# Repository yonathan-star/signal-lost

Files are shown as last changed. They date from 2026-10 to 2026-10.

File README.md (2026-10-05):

# signal-lost
Signal Lost: an interactive PCB radio that tunes into fictional transmissions

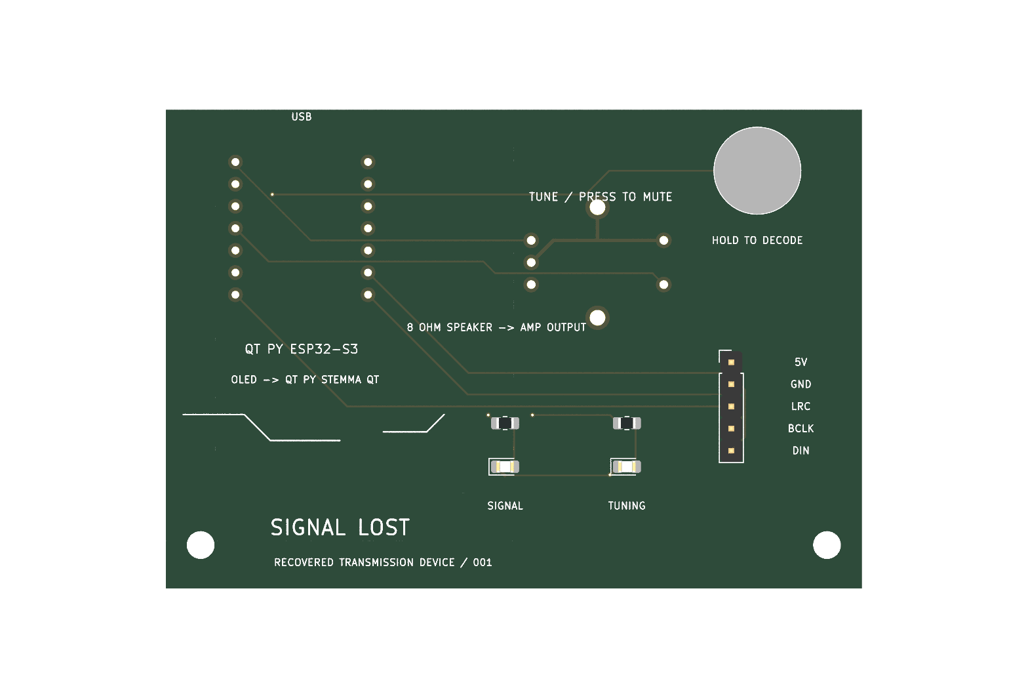
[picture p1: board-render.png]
Signal Lost PCB front render


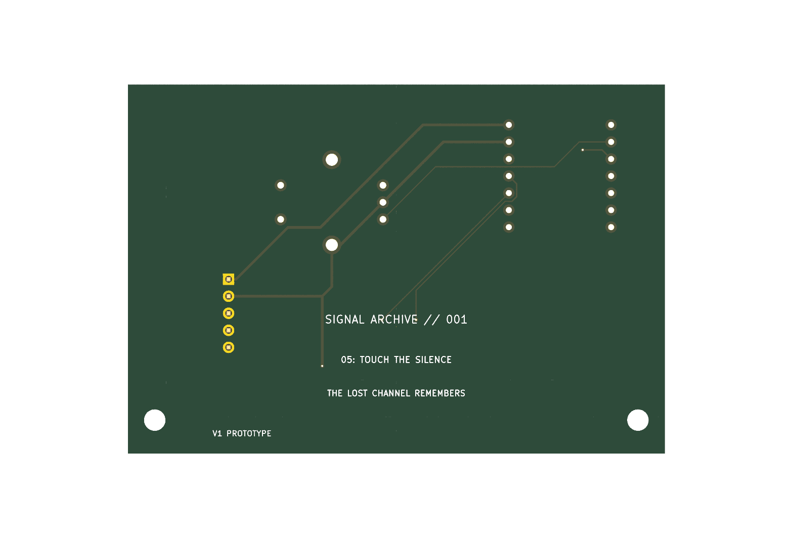
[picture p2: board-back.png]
Signal Lost PCB back render


## Engineering prototype

This repository includes an AI-assisted KiCad carrier PCB design and prototype firmware. The schematic has zero ERC errors or warnings, the board has zero DRC errors and zero unconnected pads with one touch-pad silkscreen warning, and the firmware compiles. The hardware has not been assembled or physically tested.

- [Editable KiCad project](signal-lost.kicad_pro), [schematic](signal-lost.kicad_sch), and [PCB](signal-lost.kicad_pcb)
- [Schematic PDF](schematic.pdf)
- [Firmware source and PlatformIO configuration](firmware/)
- [Parts list](bom-signal-lost.csv)
- [Gerbers and drill files](gerbers/) and [fabrication ZIP](signal-lost-gerbers.zip)
- [Assembly details, references, and remaining work](DESIGN_NOTES.md)
- [KiCad verification reports](verification/)
- [Complete design package](signal-lost-design-package.zip)

The amplifier, speaker, and OLED are external modules connected to the carrier. The enclosure and illuminated cutouts remain to be designed. Journal entries should record work actually performed by the project author.

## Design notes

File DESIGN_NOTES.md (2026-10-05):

# Signal Lost engineering prototype

This is an editable, AI-assisted engineering prototype for your inspection and learning. It is not a tested build or a claim of original student work. Read and redraw or substantially adapt the design before using it for a Half Life submission; write your own README and journal entries describing what you actually made and tested.

## What the PCB does

- An 80 × 55 mm, two-layer USB-powered carrier holds an Adafruit QT Py ESP32-S3 and a Bourns PEC11 rotary encoder with push switch.
- A 10 mm exposed copper pad acts as the hidden touch input. Two 0805 LEDs indicate tuning and signal state.
- A five-pin header feeds an external Adafruit MAX98357A I2S amplifier breakout. An 8 Ω speaker attaches to the amplifier, not to the carrier PCB.
- A 128 × 32 OLED attaches to the QT Py's built-in STEMMA QT connector using a 4-pin cable.
- The back silkscreen carries clues for the secret station. The current PCB has no illuminated cutouts or enclosure; those parts of the original idea remain to design.

## Assembly map

| Carrier J1 | Amplifier breakout |
| --- | --- |
| 1 / 5V | VIN |
| 2 / GND | GND |
| 3 / LRC | LRC |
| 4 / BCLK | BCLK |
| 5 / DIN | DIN |

Use five separate jumper wires because the breakout pin order includes other pins between these signals. Leave GAIN and SD/MODE at the breakout's default settings. Connect the speaker to the amplifier's **OUT+ and OUT−** terminals; neither speaker lead connects to ground. Solder the QT Py's 7-pin header rows into the carrier and connect the OLED to the QT Py's STEMMA QT socket. The USB-C port powers the assembly. Check the purchased encoder's pin spacing against the supplied `PEC11_Switch.kicad_mod` before ordering boards.

## Files

- `signal-lost.kicad_sch`, `signal-lost.kicad_pcb`, `signal-lost.kicad_pro`: editable KiCad 9 design.
- `SignalLost.kicad_sym`, `SignalLost.pretty/`, library tables: custom symbol and footprints needed by the design.
- `firmware/`: PlatformIO source for the QT Py ESP32-S3 4 MB flash / 2 MB PSRAM variant.
- `gerbers/` and `signal-lost-gerbers.zip`: fabrication outputs from the board design.
- `bom-signal-lost.csv`: parts list with current individual prices and vendor links; **$46.58 parts subtotal** before PCB fabrication, shipping, tax, USB cable and enclosure. Confirm prices before ordering.
- `board-render.png`, `board-back.png`, `schematic.pdf`: visual references.

## Verification and remaining work

- KiCad schematic ERC: **0 errors, 0 warnings**.
- KiCad PCB DRC: **0 errors, 0 unconnected pads**, and one warning because the front silkscreen is clipped by the intentionally exposed touch pad.
- PlatformIO firmware build: **successful** for `adafruit_qtpy_esp32s3_n4r2`.
- No hardware has been assembled, powered, flashed, or physically tested. Touch thresholds, encoder direction, OLED address, sound level, and cable fit need bench testing. Keep the initial volume low with the 1 W speaker.
- The current drawing is a carrier plus breakout modules, not a complete enclosed pocket device. Design an enclosure, mounting for the display/speaker/amp, and any light windows after measuring the actual parts.

## Technical references

- [Adafruit QT Py ESP32-S3 documentation](https://learn.adafruit.com/adafruit-qt-py-esp32-s3)
- [Adafruit MAX98357A amplifier wiring and output details](https://learn.adafruit.com/adafruit-max98357-i2s-class-d-mono-amp)
- [Adafruit's PEC11 encoder board](https://github.com/adafruit/Adafruit-I2C-QT-Rotary-Encoder-PCB)
- [Same Sky speaker specifications](https://www.digikey.com/en/products/detail/same-sky-formerly-cui-devices/CMS-30204-18L250/24398508)

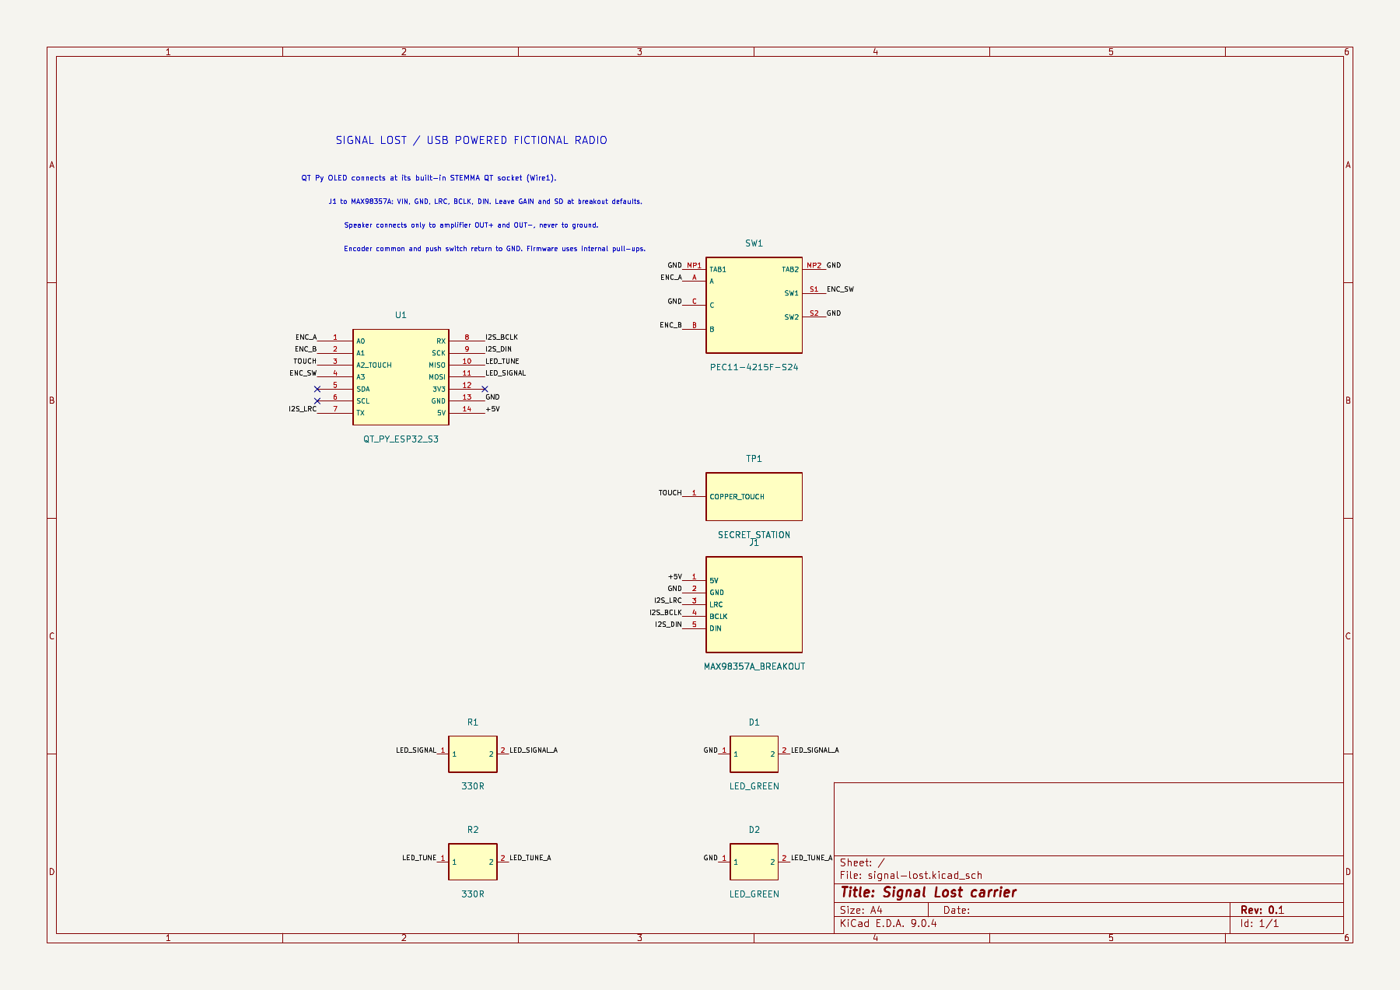
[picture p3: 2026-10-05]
schematic.png

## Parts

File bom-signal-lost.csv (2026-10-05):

reference | part | quantity | unit_price_usd | line_total_usd | vendor | url | notes
U1 | Adafruit QT Py ESP32-S3 4MB/2MB PSRAM #5700 | 1 | 12.50 | 12.50 | DigiKey | https://www.digikey.com/en/products/detail/adafruit-industries-llc/5700/21283799 | Solder header directly into carrier; USB-C powered
External amp | Adafruit MAX98357A I2S amp breakout #3006 | 1 | 5.95 | 5.95 | Adafruit | https://www.adafruit.com/product/3006 | Assembled breakout; wire to J1
External display | Adafruit 0.91 inch 128x32 STEMMA QT OLED #4440 | 1 | 12.50 | 12.50 | Adafruit | https://www.adafruit.com/product/4440 | Connect to QT Py STEMMA QT socket
SW1 | Adafruit/Bourns rotary encoder with push switch and knob #377 | 1 | 4.50 | 4.50 | Adafruit | https://www.adafruit.com/product/377 | PEC11 switch footprint; verify purchased pin pattern
External speaker | Same Sky CMS-30204-18L250 8 ohm 1 watt speaker | 1 | 2.74 | 2.74 | DigiKey | https://www.digikey.com/en/products/detail/same-sky-formerly-cui-devices/CMS-30204-18L250/24398508 | Connect only to amp speaker terminals
Display cable | Adafruit STEMMA QT/Qwiic 50mm cable #4399 | 1 | 0.95 | 0.95 | Adafruit | https://www.adafruit.com/product/4399 | 4-pin JST SH cable
U1/J1 headers | Adafruit male break-away header pack #392 | 1 | 4.95 | 4.95 | Adafruit | https://www.adafruit.com/product/392 | Cut two 7-pin strips plus one 5-pin strip
Amp leads | Adafruit female-female 3-inch jumper wire pack #1951 | 1 | 1.95 | 1.95 | Adafruit | https://www.adafruit.com/product/1951 | Use five independent jumpers to amp pins
R1,R2 | Yageo RC0805FR-10330RL 330 ohm 0805 resistor | 2 | 0.10 | 0.20 | DigiKey | https://www.digikey.com/en/products/detail/yageo/RC0805FR-10330RL/13694160 | Hand solder 0805
D1,D2 | Lite-On LTST-C170GKT green 0805 LED | 2 | 0.17 | 0.34 | DigiKey | https://www.digikey.com/en/products/detail/liteon/LTST-C170GKT/269226 | Check polarity before soldering
PCB | 2-layer 80 x 55 mm fabrication | 1 |  |  | Choose PCB fab |  | Quote PCB price and shipping before ordering
TOTAL PARTS ONLY | Excludes PCB, shipping, tax, USB cable and enclosure |  |  | 46.58 |  |  | Prices and availability may change

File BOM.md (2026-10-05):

# Signal Lost — bill of materials

<!-- Generated by Half Life from project cmuvjrnhl00o001pyzu3rbkd7. Edits here are overwritten on the next sync. -->
<!-- Generated: 1970-01-01T00:00:00.000Z -->

> [!NOTE]
> This parts list is mirrored from [Half Life](https://halflife.hackclub.com). Editing it here will not change the platform's copy, and the next sync overwrites this file.

| Week | Tier | Parts funding |
| --- | --- | --- |
| Week 1 | Tier 2 | $65.00 |

_No parts listed yet._

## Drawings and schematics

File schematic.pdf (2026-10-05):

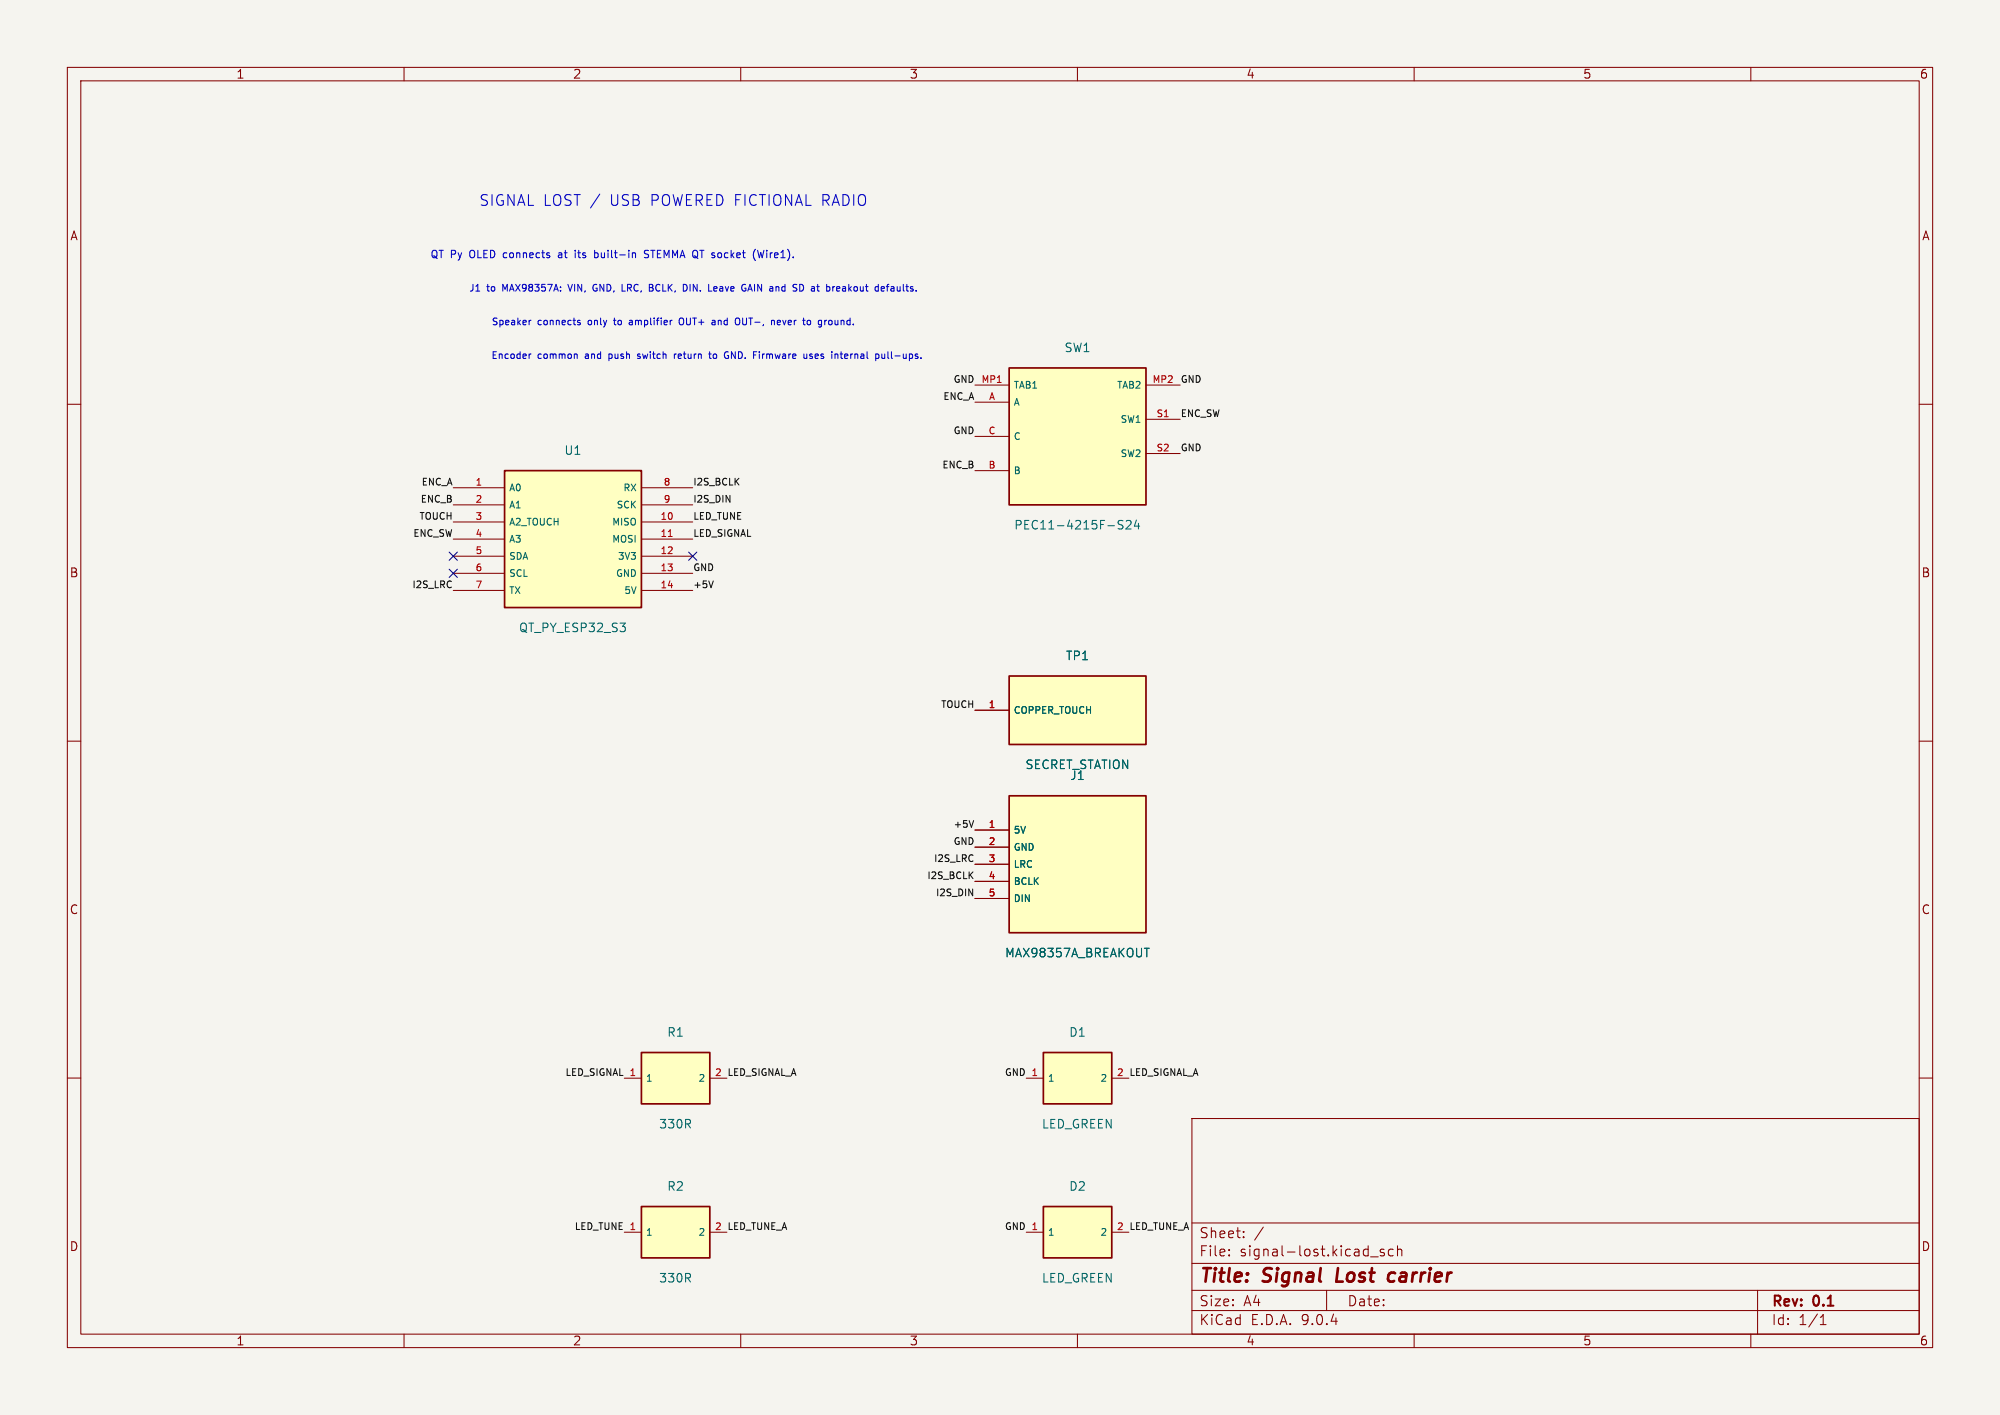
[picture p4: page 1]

Id: 1/1 Title: Signal Lost carrier File: signal-lost.kicad_sch Sheet: /

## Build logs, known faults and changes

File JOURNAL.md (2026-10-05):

# Signal Lost — devlog

<!-- Generated by Half Life from project cmuvjrnhl00o001pyzu3rbkd7. Edits here are overwritten on the next sync. -->
<!-- Generated: 1970-01-01T00:00:00.000Z -->

> [!NOTE]
> This devlog is mirrored from [Half Life](https://halflife.hackclub.com). Editing it here will not change the platform's copy, and the next sync overwrites this file.

> I’m making a pocket-sized “radio” that tunes into fictional transmissions. Turning a dial changes the sounds and lights, while a hidden touch-sensitive spot unlocks a secret station. The PCB itself will look like a strange piece of recovered technology, with glowing cutouts and clues printed on the back.

| Week | Tier | Hours logged | Entries |
| --- | --- | --- | --- |
| Week 1 | Tier 2 | 0h | 0 |

_No entries logged yet._

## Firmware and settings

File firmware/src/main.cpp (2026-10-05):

// Signal Lost: exploratory firmware reference, not a tested physical build.
// Target: Adafruit QT Py ESP32-S3 (4 MB flash, 2 MB PSRAM), USB powered.

#include <Arduino.h>
#include <Wire.h>
#include <Adafruit_GFX.h>
#include <Adafruit_SSD1306.h>
#include <driver/i2s.h>
#include <math.h>
#include <cstring>

namespace {
constexpr uint8_t kEncoderA = A0;
constexpr uint8_t kEncoderB = A1;
constexpr uint8_t kTouch = A2;
constexpr uint8_t kEncoderButton = A3;
constexpr uint8_t kI2sBclk = TX;
constexpr uint8_t kI2sLrc = RX;
constexpr uint8_t kI2sData = SCK;
constexpr uint8_t kLedSignal = MOSI;
constexpr uint8_t kLedTuning = MISO;
constexpr uint32_t kSampleRate = 16000;
constexpr uint8_t kStationCount = 4;
constexpr uint8_t kSecretStation = 4;
constexpr uint8_t kScreenAddress = 0x3C;

Adafruit_SSD1306 screen(128, 32, &Wire1, -1);
bool screenReady = false;
volatile uint8_t station = 0;
volatile bool playing = true;
volatile bool secretUnlocked = false;

const char* const kNames[] = {
    "NIGHT WEATHER", "DISTRESS", "NUMBERS", "DEEP SPACE", "UNKNOWN"};
const char* const kFrequency[] = {
    "88.1", "91.7", "104.3", "117.9", "???.?"};

uint8_t encoderPrevious = 0;
int8_t encoderAccumulator = 0;
bool buttonPrevious = HIGH;
uint32_t buttonChangedAt = 0;
bool buttonStable = HIGH;
uint32_t touchBaseline = 0;
uint8_t touchSamples = 0;
bool touchLatched = false;
uint32_t lastDrawAt = 0;
uint32_t lastDebugAt = 0;

// An LCG provides reproducible static. This is decorative audio, not real radio reception.
uint32_t noiseState = 0x48616C66;
float phaseA = 0.0f;
float phaseB = 0.0f;
uint32_t audioSamples = 0;

int16_t nextAudioSample() {
  const uint8_t current = station;
  const float t = static_cast<float>(audioSamples++) / kSampleRate;
  noiseState = noiseState * 1664525u + 1013904223u;
  const float noise = static_cast<int32_t>(noiseState) / 2147483648.0f;
  float value = 0.0f;
  float frequencyA = 0.0f;
  float frequencyB = 0.0f;

  switch (current) {
    case 0: { // Night weather: low drone with a soft static bed.
      frequencyA = 110.0f;
      value = 0.30f * sinf(phaseA) + 0.10f * noise;
      break;
    }
    case 1: { // Distress: three short pulses, three long, three short.
      constexpr char sos[] = "101010111011101110101010000000";
      const uint32_t slot = (audioSamples / (kSampleRate / 10)) % (sizeof(sos) - 1);
      frequencyA = 720.0f;
      value = sos[slot] == '1' ? 0.40f * sinf(phaseA) : 0.04f * noise;
      break;
    }
    case 2: { // Numbers station: regular two-tone coded pulses.
      const uint32_t slot = (audioSamples / (kSampleRate / 8)) % 16;
      frequencyA = (slot & 1u) ? 880.0f : 660.0f;
      value = (slot % 4u == 3u) ? 0.02f * noise : 0.28f * sinf(phaseA);
      break;
    }
    case 3: { // Deep space: slow beat between two nearby tones.
      frequencyA = 165.0f;
      frequencyB = 168.0f;
      value = 0.22f * sinf(phaseA) + 0.22f * sinf(phaseB) + 0.05f * noise;
      break;
    }
    default: { // Hidden station: alternating signal and silence.
      frequencyA = 444.0f + 60.0f * sinf(t * 0.55f);
      const bool gate = ((audioSamples / (kSampleRate / 3)) % 6u) < 4u;
      value = gate ? 0.33f * sinf(phaseA) : 0.0f;
      break;
    }
  }

  phaseA += 2.0f * PI * frequencyA / kSampleRate;
  phaseB += 2.0f * PI * frequencyB / kSampleRate;
  if (phaseA >= 2.0f * PI) phaseA -= 2.0f * PI;
  if (phaseB >= 2.0f * PI) phaseB -= 2.0f * PI;
  // Software volume cap protects the small speaker during this draft.
  const float scaled = playing ? value * 0.45f : 0.0f;
  return static_cast<int16_t>(constrain(scaled, -1.0f, 1.0f) * 32767.0f);
}

void audioTask(void*) {
  int16_t samples[256];
  for (;;) {
    for (auto& sample : samples) sample = nextAudioSample();
    size_t written = 0;
    i2s_write(I2S_NUM_0, samples, sizeof(samples), &written, portMAX_DELAY);
  }
}

bool beginAudio() {
  i2s_config_t config{};
  config.mode = static_cast<i2s_mode_t>(I2S_MODE_MASTER | I2S_MODE_TX);
  config.sample_rate = kSampleRate;
  config.bits_per_sample = I2S_BITS_PER_SAMPLE_16BIT;
  config.channel_format = I2S_CHANNEL_FMT_ONLY_LEFT;
  config.communication_format = I2S_COMM_FORMAT_STAND_I2S;
  config.intr_alloc_flags = 0;
  config.dma_buf_count = 6;
  config.dma_buf_len = 256;
  config.use_apll = false;
  config.tx_desc_auto_clear = true;
  config.fixed_mclk = 0;

  i2s_pin_config_t pins{};
  pins.bck_io_num = kI2sBclk;
  pins.ws_io_num = kI2sLrc;
  pins.data_out_num = kI2sData;
  pins.data_in_num = I2S_PIN_NO_CHANGE;
  if (i2s_driver_install(I2S_NUM_0, &config, 0, nullptr) != ESP_OK) return false;
  if (i2s_set_pin(I2S_NUM_0, &pins) != ESP_OK) return false;
  xTaskCreatePinnedToCore(audioTask, "radio-audio", 4096, nullptr, 2, nullptr, 0);
  return true;
}

void scanEncoder() {
  static constexpr int8_t transitions[16] = {
      0, -1, 1, 0, 1, 0, 0, -1, -1, 0, 0, 1, 0, 1, -1, 0};
  const uint8_t now = (digitalRead(kEncoderA) << 1) | digitalRead(kEncoderB);
  const uint8_t index = (encoderPrevious << 2) | now;
  encoderPrevious = now;
  encoderAccumulator += transitions[index];
  if (encoderAccumulator >= 4 || encoderAccumulator <= -4) {
    const int direction = encoderAccumulator > 0 ? 1 : -1;
    encoderAccumulator = 0;
    station = (station + direction + kStationCount) % kStationCount;
    Serial.printf("Station %u: %s\n", station, kNames[station]);
  }
}

void scanButton() {
  const bool now = digitalRead(kEncoderButton);
  if (now != buttonPrevious) buttonChangedAt = millis();
  buttonPrevious = now;
  if (millis() - buttonChangedAt > 30 && now != buttonStable) {
    buttonStable = now;
    if (now == LOW) playing = !playing;
  }
}

void scanTouch() {
  const uint32_t raw = touchRead(kTouch);
  if (touchBaseline == 0) touchBaseline = raw;
  const uint32_t difference = raw > touchBaseline ? raw - touchBaseline : touchBaseline - raw;
  const uint32_t threshold = touchBaseline / 7 > 20 ? touchBaseline / 7 : 20;
  if (difference > threshold) {
    if (touchSamples < 8) ++touchSamples;
  } else {
    touchSamples = 0;
    touchLatched = false;
    touchBaseline = (touchBaseline * 63u + raw) / 64u;
  }
  if (touchSamples >= 4 && !touchLatched) {
    touchLatched = true;
    secretUnlocked = true;
    station = kSecretStation;
    playing = true;
    Serial.printf("Secret touch: raw=%lu baseline=%lu\n",
                  static_cast<unsigned long>(raw),
                  static_cast<unsigned long>(touchBaseline));
  }
  if (millis() - lastDebugAt >= 1000) {
    lastDebugAt = millis();
    Serial.printf("Touch raw=%lu baseline=%lu threshold=%lu\n",
                  static_cast<unsigned long>(raw),
                  static_cast<unsigned long>(touchBaseline),
                  static_cast<unsigned long>(threshold));
  }
}

void drawDisplay() {
  if (!screenReady || millis() - lastDrawAt < 80) return;
  lastDrawAt = millis();
  screen.clearDisplay();
  screen.setTextSize(1);
  screen.setTextColor(SSD1306_WHITE);
  screen.setCursor(0, 0);
  screen.print("SIGNAL LOST   FM ");
  screen.print(kFrequency[station]);
  screen.setTextSize(strlen(kNames[station]) > 10 ? 1 : 2);
  screen.setCursor(0, 12);
  screen.print(kNames[station]);
  screen.display();
}

void updateLeds() {
  const uint32_t now = millis();
  digitalWrite(kLedTuning, ((now / 120) % 2u) == 0u);
  digitalWrite(kLedSignal, playing && (((now / 300) % 3u) != 0u));
}
} // namespace

void setup() {
  Serial.begin(115200);
  pinMode(kEncoderA, INPUT_PULLUP);
  pinMode(kEncoderB, INPUT_PULLUP);
  pinMode(kEncoderButton, INPUT_PULLUP);
  pinMode(kLedSignal, OUTPUT);
  pinMode(kLedTuning, OUTPUT);
  encoderPrevious = (digitalRead(kEncoderA) << 1) | digitalRead(kEncoderB);

  Wire1.begin(SDA1, SCL1);
  screenReady = screen.begin(SSD1306_SWITCHCAPVCC, kScreenAddress);
  if (!screenReady) Serial.println("OLED not found; continuing without display");
  if (!beginAudio()) Serial.println("I2S setup failed");
  Serial.println("Signal Lost exploratory firmware started");
}

void loop() {
  scanEncoder();
  scanButton();
  scanTouch();
  drawDisplay();
  updateLeds();
  delay(2);
}
